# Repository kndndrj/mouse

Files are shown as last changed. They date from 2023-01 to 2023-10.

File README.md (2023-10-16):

# Mouse

Computer mouse from scratch.

This repository serves as an appendix to my master thesis.

New features and bugfixes won't be added to this repository.
I plan on separating different parts of the repository into
a bigger project sometime in the future. If you come across
this repository before I do that, feel free to open an issue here.

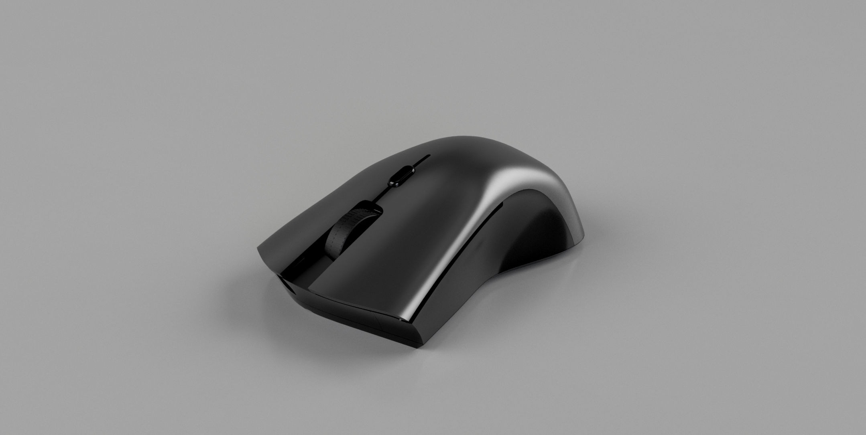
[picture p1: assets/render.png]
render


## Overview

This repository contains blueprints for building a computer mouse.

### PCB

The pcb is made using Kicad with components from LCSC, to support assembly service from JLCPCB.

[more](pcb/)

### Housing

Housing (or case) is designed in Fusion360 and is meant to be 3D printed using SLS (also available on JLCPCB).

[more](housing/)

### Firmware

First iteration of the firmware was written in C using libopencm3 library.
Due to a lack of higher level ergonomics and support for board specific abstractions,
it was later re-written in Rust.

The new version of firmware is split into 2 parts:

- **Drivers for various components** (e.g. sensor, encoder...) are exposed as a library using embedded-hal
  traits as abstraction. It is intended to be portable across different hardware and possibly used in
  other mouse-related projects.
- **Board specific implementation** is essentially just glue-code between hardware specifics and modules
  from the forementioned library.

[more - C](firmware-c/)

[more - Rust](firmware-rust/)

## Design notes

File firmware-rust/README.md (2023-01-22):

# Mouse Firmware in Rust

Rust firmware for computer mice.

This repo is split into two parts:

- `mouse-libs`

  Drivers for mouse components using embedded-hal interfaces.

  [more](mouse-libs/README.md).

- `mouse-fw`

  Specific firmware implementation using the forementioned libraries.

  [more](mouse-fw/README.md).

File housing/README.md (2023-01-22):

# Mouse Housing

Housing for the PCB, designed in Fusion360

[`assembly.f3z`](assembly.f3z) is used for development, then it's exported to `.step`
and `.stl` for previewing and manufacturing.

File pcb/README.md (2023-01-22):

# Mouse PCB
Repository for the mouse circuit board schematics.

Some of the features are:
- PMW3360DM sensor
- STM32F042K6T6 MCU
- Hardware debouncing
- Expansion pins for future upgrades
- USB-C

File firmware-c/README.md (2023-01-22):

# Mouse Firmware in C

Note: Abandoned due to re-implementation in Rust. You might still find something useful when tinkering around here.

Set up the build environment with (order of crossfile flags is important):

```sh
meson setup --cross-file=crossfiles/main.ini --cross-file=crossfiles/stm32/f0.ini build
```

And then compile the code:

```sh
meson compile -C build
```

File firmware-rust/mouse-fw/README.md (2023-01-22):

# Mouse Firmware in Rust - Implementation

Firmware implementation for mouse-pcb.

## Flashing

1. Build

   ```sh
   cargo build --release # for production release
   # or
   cargo build --features="disable_usb" # for dev build without usb support - for debugging
   ```

2. "Extract" the binary

   ```sh
      arm-none-eabi-objcopy -O binary target/thumbv6m-none-eabi/release/mouse-fw-rust out.bin
   ```

3. Flash using your debug probe

   ```sh
   # example using st-link
   st-flash write out.bin 0x08000000
   ```

4. Debug (for development)
   
   Use openocd/st-util/... to set up the gdb server and connect to it using arm-none-eabi-gdb

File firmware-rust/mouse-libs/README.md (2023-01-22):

# Mouse Firmware in Rust - Library

Building blocks for writing your own firmware. It uses "interfaces"
defined by embedded-hal crate to abstract away the hardware. If you want
to use this in your firmware, simply provide the required parameters
(usually in form of trait implementation) and you are good to go.
example:

```rust
// ...init code

// init the parts that implement required traits
let gpioa = p.GPIOA.split(&mut rcc);
let (
    spi_cs,
    spi_sck,
    spi_miso,
    spi_mosi,
    pmw_reset,
) = cortex_m::interrupt::free(move |cs| {
    (
        // SPI pins
        gpioa.pa4.into_push_pull_output(cs),
        gpioa.pa5.into_alternate_af0(cs),
        gpioa.pa6.into_alternate_af0(cs),
        gpioa.pa7.into_alternate_af0(cs),
        // PMW3360 reset pin
        gpioa.pa10.into_push_pull_output(cs),
    )
});
let spi = Spi::spi1(
    p.SPI1,
    (spi_sck, spi_miso, spi_mosi),
    MODE,
    1.mhz(),
    &mut rcc,
);

// finally use that to create a new instance of the driver
let mut pmw = Pmw3360::new(spi, spi_cs, pmw_reset, delay);
// ...
```

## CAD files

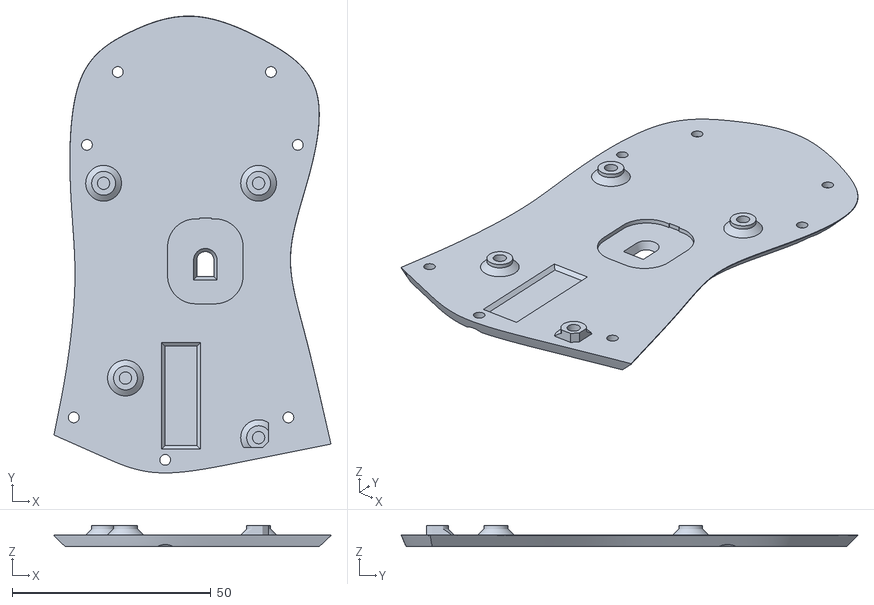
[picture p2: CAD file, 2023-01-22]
housing/stl/bottom.stl
69.7 x 114.9 x 5.40

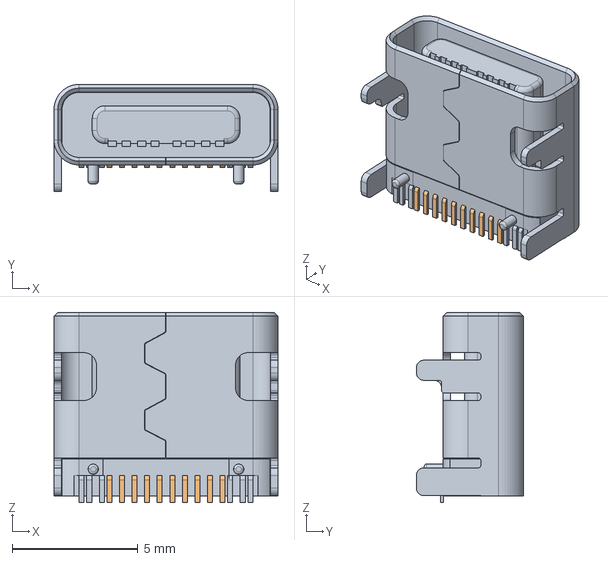
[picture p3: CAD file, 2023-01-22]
pcb/3d/usb_c_u262-16xn-4bvc11.step
8.90 x 4.26 x 7.56 mm

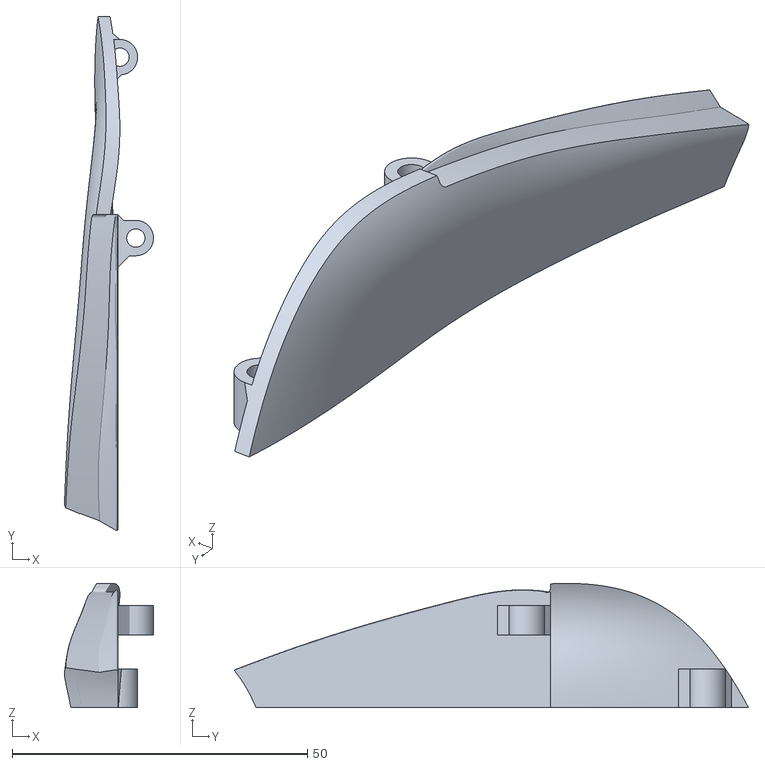
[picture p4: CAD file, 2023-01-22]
housing/stl/right.stl
15.1 x 87.1 x 21.0

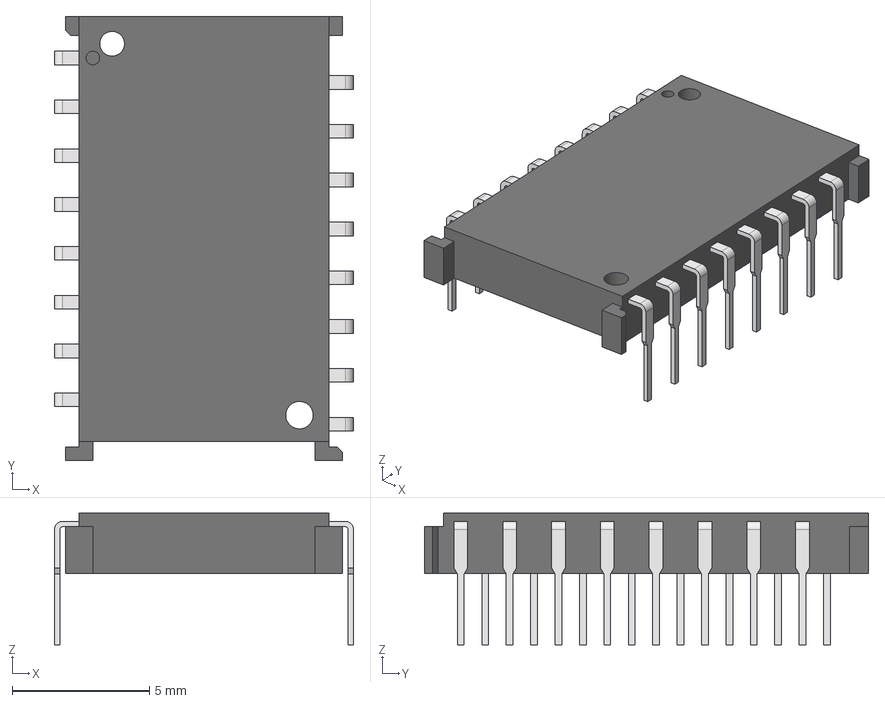
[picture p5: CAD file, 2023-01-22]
pcb/3d/sensor_pmw3360dm.step
10.9 x 16.2 x 4.81 mm
Lead x 8
Lead(Mirror) x 8

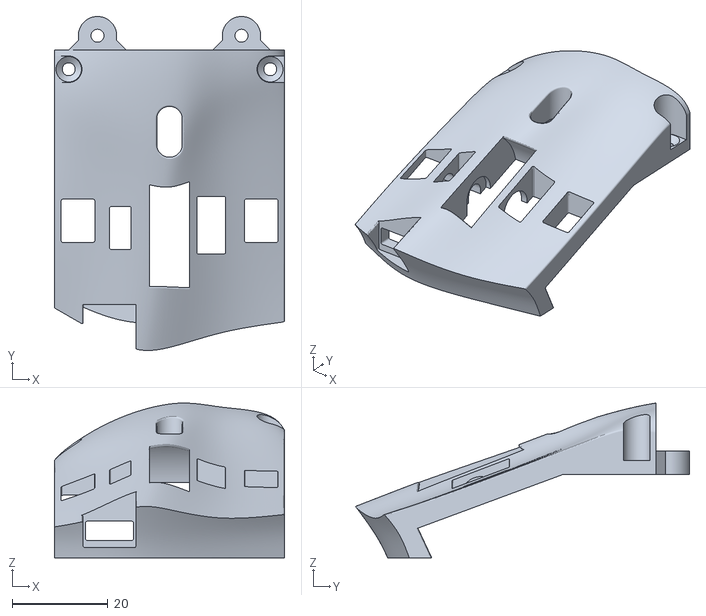
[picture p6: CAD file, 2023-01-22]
housing/stl/middle.stl
48.0 x 69.6 x 32.3

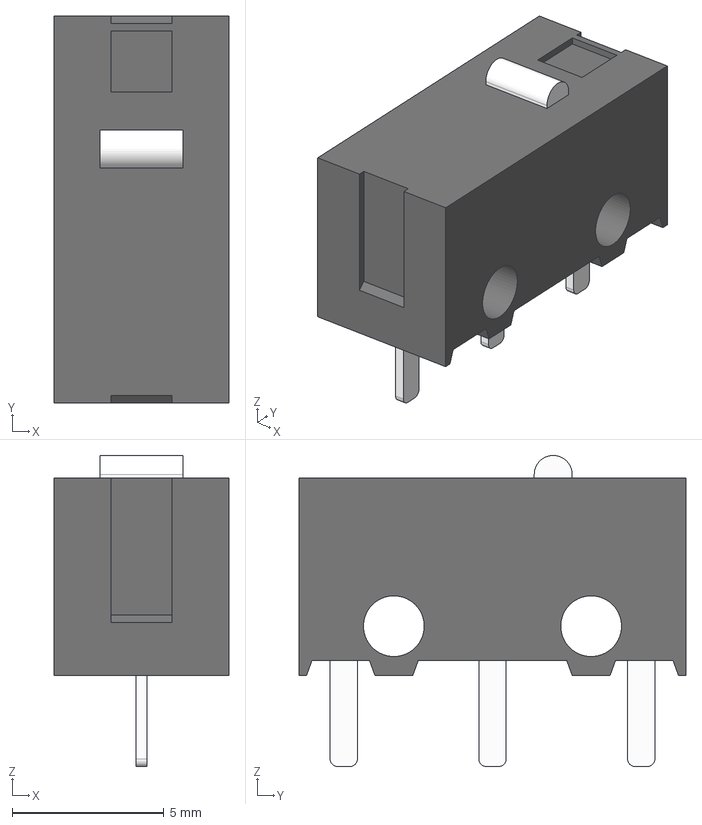
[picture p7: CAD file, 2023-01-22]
pcb/3d/switch_d2fc-f-7n.step
5.75 x 12.8 x 10.2 mm
Switch Body
Pin 2
Button
Pin 3
Pin 1

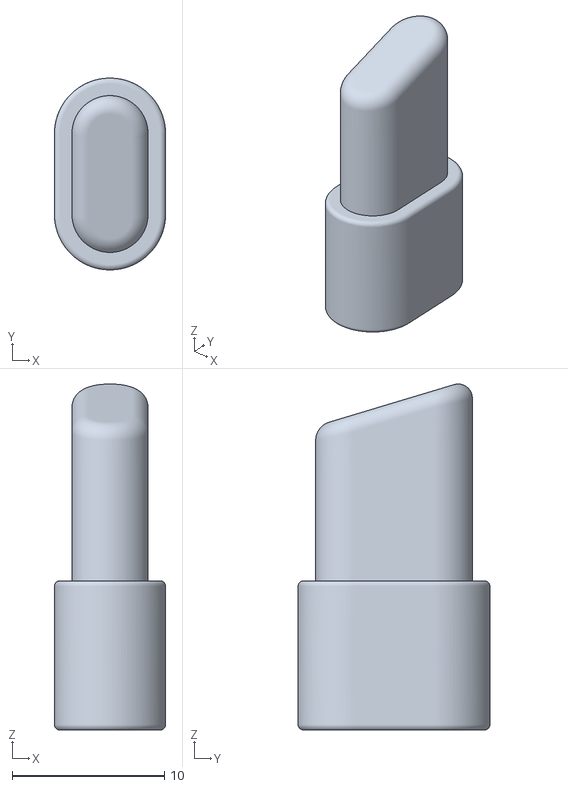
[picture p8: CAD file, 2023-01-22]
housing/stl/button.stl
7.30 x 12.6 x 22.7

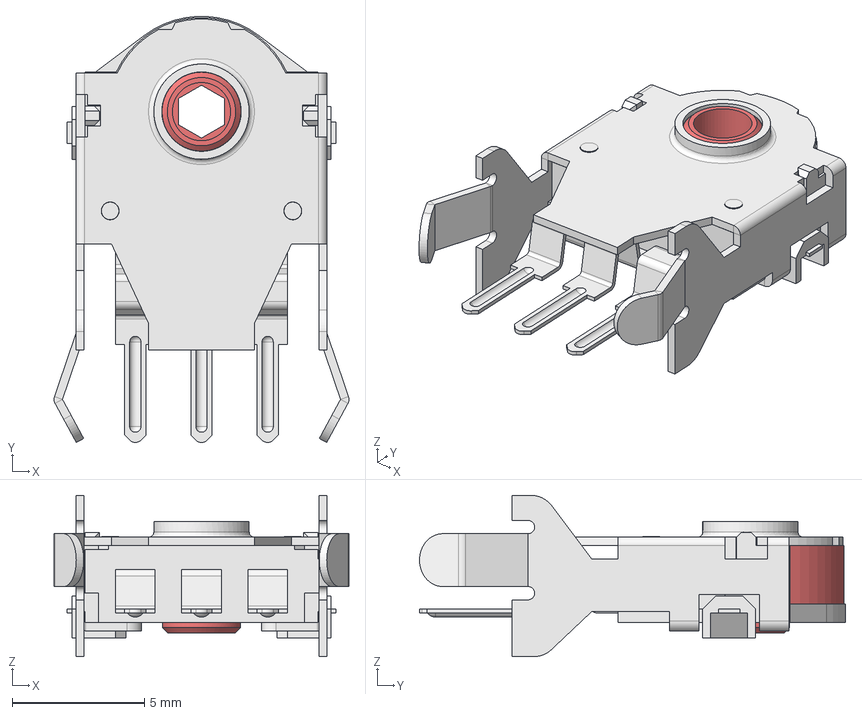
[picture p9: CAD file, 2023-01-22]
pcb/3d/encoder_ec10_9mm.step
11.1 x 16.1 x 6.10 mm

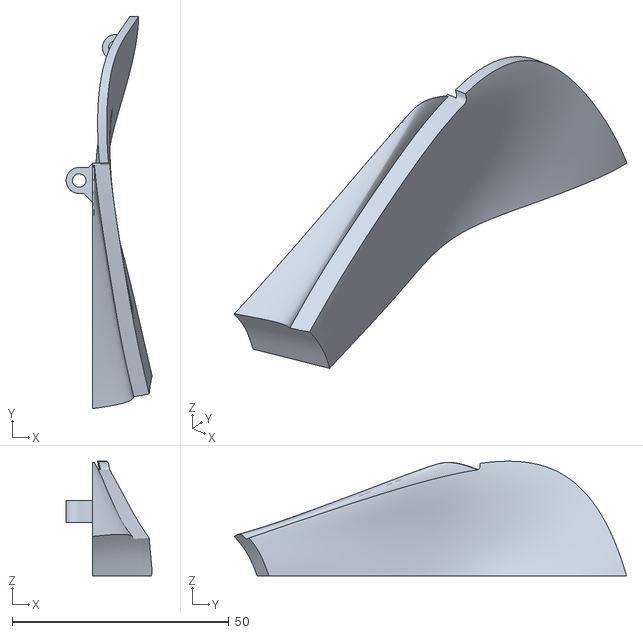
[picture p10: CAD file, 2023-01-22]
housing/stl/left.stl
19.8 x 90.4 x 26.4

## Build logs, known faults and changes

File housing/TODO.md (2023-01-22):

# Mouse Housing TODO

- Add shape joints between parts
- Is there a way of convert to stl using CI

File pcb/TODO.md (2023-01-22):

# Mouse PCB TODO

- Flip sensor 180 degrees (keep lens holes on exactly the same position!!!)
- Adjust encoder clearance (lower right corner touches a cap)
- Left and right expansion pins should have the same arrangement
- Do something with Boot0 pin (must be connected to GND - maybe through a button or a switch?)
- Connect encoder to timer input pins

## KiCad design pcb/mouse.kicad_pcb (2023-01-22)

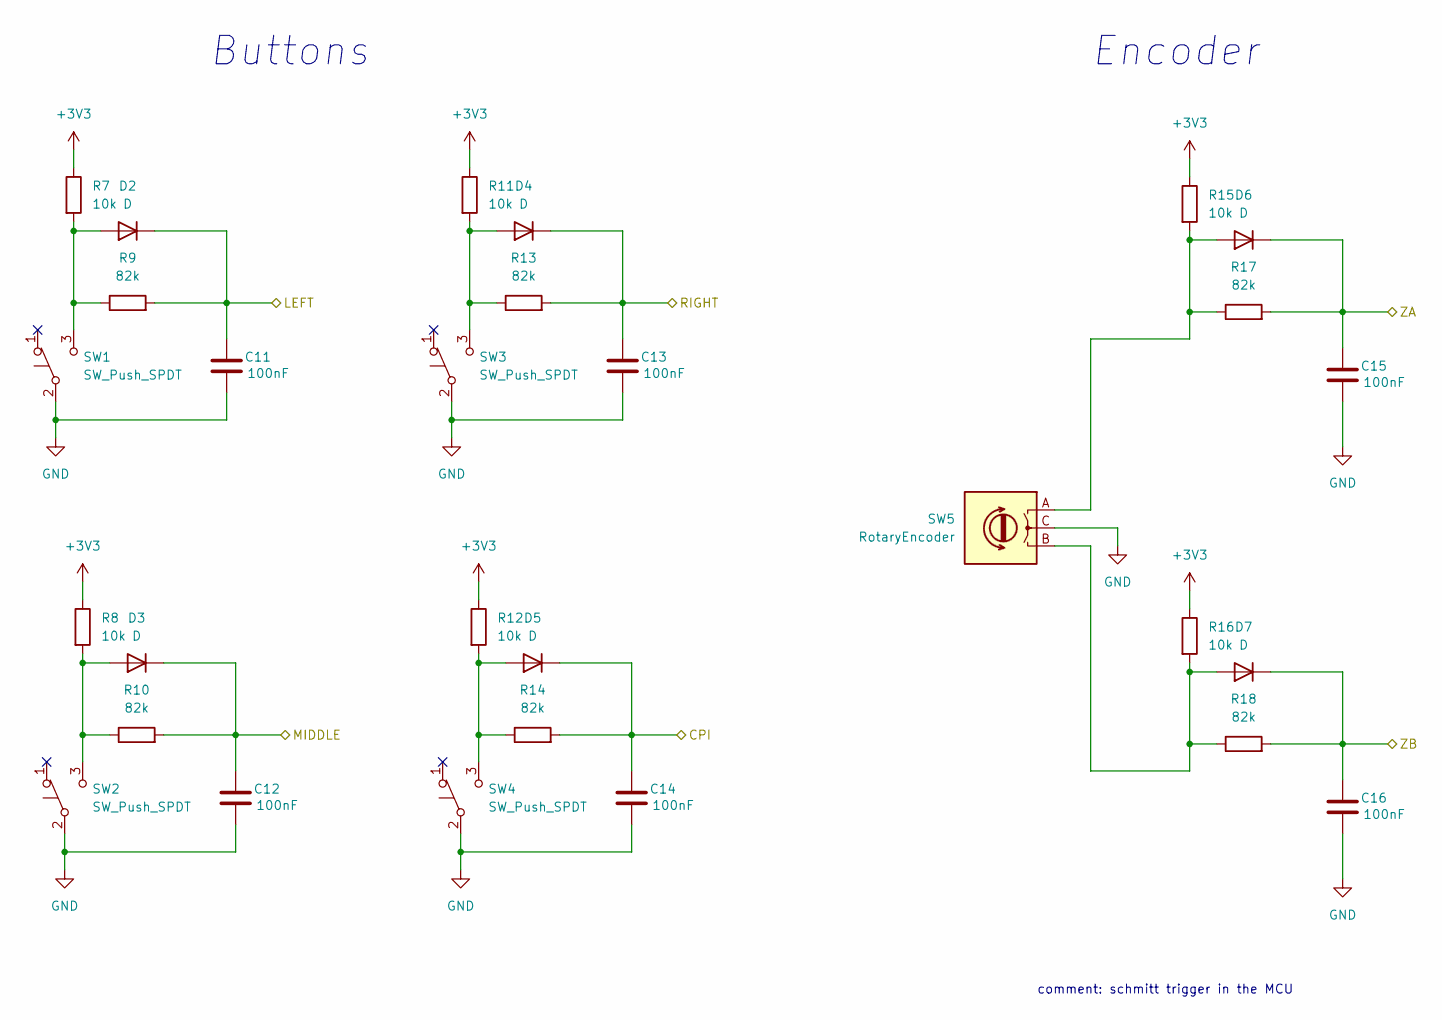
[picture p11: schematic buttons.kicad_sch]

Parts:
C11, C12, C13, C14, C15, C16: 100nF; C_0603_1608Metric; LCSC C14663
D2, D3, D4, D5, D6, D7: D; D_SOD-123F; LCSC C64898
R7, R8, R11, R12, R15, R16: 10k; R_0603_1608Metric; LCSC C25804
R9, R10, R13, R14, R17, R18: 82k; R_0603_1608Metric; LCSC C23254
SW1, SW2, SW3, SW4: SW_Push_SPDT; mouse_switch
SW5: RotaryEncoder; mouse_encoder

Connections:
+3V3: R7.1, R8.1, R11.1, R12.1, R15.1, R16.1; also elsewhere on the board
/buttons/CPI: C14.1, D5.1 (K), R14.2; also elsewhere on the board
/buttons/LEFT: C11.1, D2.1 (K), R9.2; also elsewhere on the board
/buttons/MIDDLE: C12.1, D3.1 (K), R10.2; also elsewhere on the board
/buttons/RIGHT: C13.1, D4.1 (K), R13.2; also elsewhere on the board
/buttons/ZA: C15.1, D6.1 (K), R17.2; also elsewhere on the board
/buttons/ZB: C16.1, D7.1 (K), R18.2; also elsewhere on the board
GND: C11.2, C12.2, C13.2, C14.2, C15.2, C16.2, SW1.2 (B), SW2.2 (B), SW3.2 (B), SW4.2 (B), SW5.C; also elsewhere on the board
unnamed: D2.2 (A), R7.2, R9.1, SW1.3 (C)
unnamed: D3.2 (A), R8.2, R10.1, SW2.3 (C)
unnamed: D4.2 (A), R11.2, R13.1, SW3.3 (C)
unnamed: D5.2 (A), R12.2, R14.1, SW4.3 (C)
unnamed: D6.2 (A), R15.2, R17.1, SW5.A
unnamed: D7.2 (A), R16.2, R18.1, SW5.B

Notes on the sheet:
Encoder
Buttons
comment: schmitt trigger in the MCU

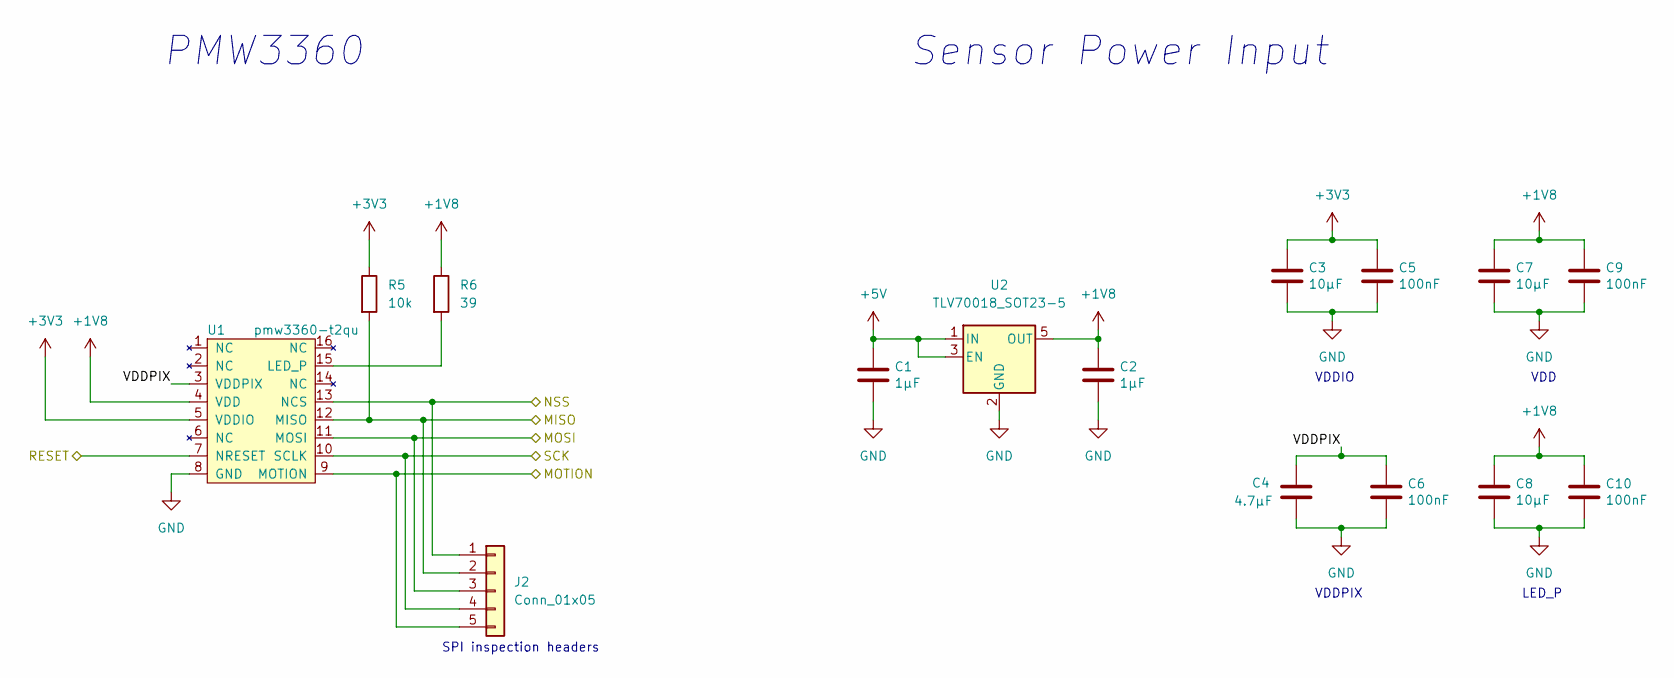
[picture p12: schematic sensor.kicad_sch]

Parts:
C1, C2: 1μF; C_0603_1608Metric; LCSC C15849
C3, C7, C8: 10μF; C_0603_1608Metric; LCSC C19702
C4: 4.7μF; C_0603_1608Metric; LCSC C19666
C5, C6, C9, C10: 100nF; C_0603_1608Metric; LCSC C14663
J2: Conn_01x05; PinHeader_1x05_P2.54mm_Vertical
R5: 10k; R_0603_1608Metric; LCSC C25804
R6: 39; R_0603_1608Metric; LCSC C227890
U1: pmw3360-t2qu
U2: TLV70018_SOT23-5; SOT-23-5; LCSC C79924

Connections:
+1V8: C2.1, C7.1, C8.1, C9.1, C10.1, R6.1, U1.4 (VDD), U2.5 (OUT)
+3V3: C3.1, C5.1, R5.1, U1.5 (VDDIO); also elsewhere on the board
+5V: C1.1, U2.1 (IN), U2.3 (EN); also elsewhere on the board
/mcu/SENSOR_MISO: J2.2, R5.2, U1.12 (MISO); also elsewhere on the board
/mcu/SENSOR_MOSI: J2.3, U1.11 (MOSI); also elsewhere on the board
/mcu/SENSOR_MOTION: J2.5, U1.9 (MOTION); also elsewhere on the board
/mcu/SENSOR_NSS: J2.1, U1.13 (NCS); also elsewhere on the board
/mcu/SENSOR_RESET: U1.7 (NRESET); also elsewhere on the board
/mcu/SENSOR_SCK: J2.4, U1.10 (SCLK); also elsewhere on the board
/sensor/VDDPIX: C4.1, C6.1, U1.3 (VDDPIX)
GND: C1.2, C2.2, C3.2, C4.2, C5.2, C6.2, C7.2, C8.2, C9.2, C10.2, U1.8 (GND), U2.2 (GND); also elsewhere on the board
unnamed: R6.2, U1.15 (LED_P)

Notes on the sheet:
VDDIO
VDD
SPI inspection headers
Sensor Power Input
LED_P
VDDPIX
PMW3360

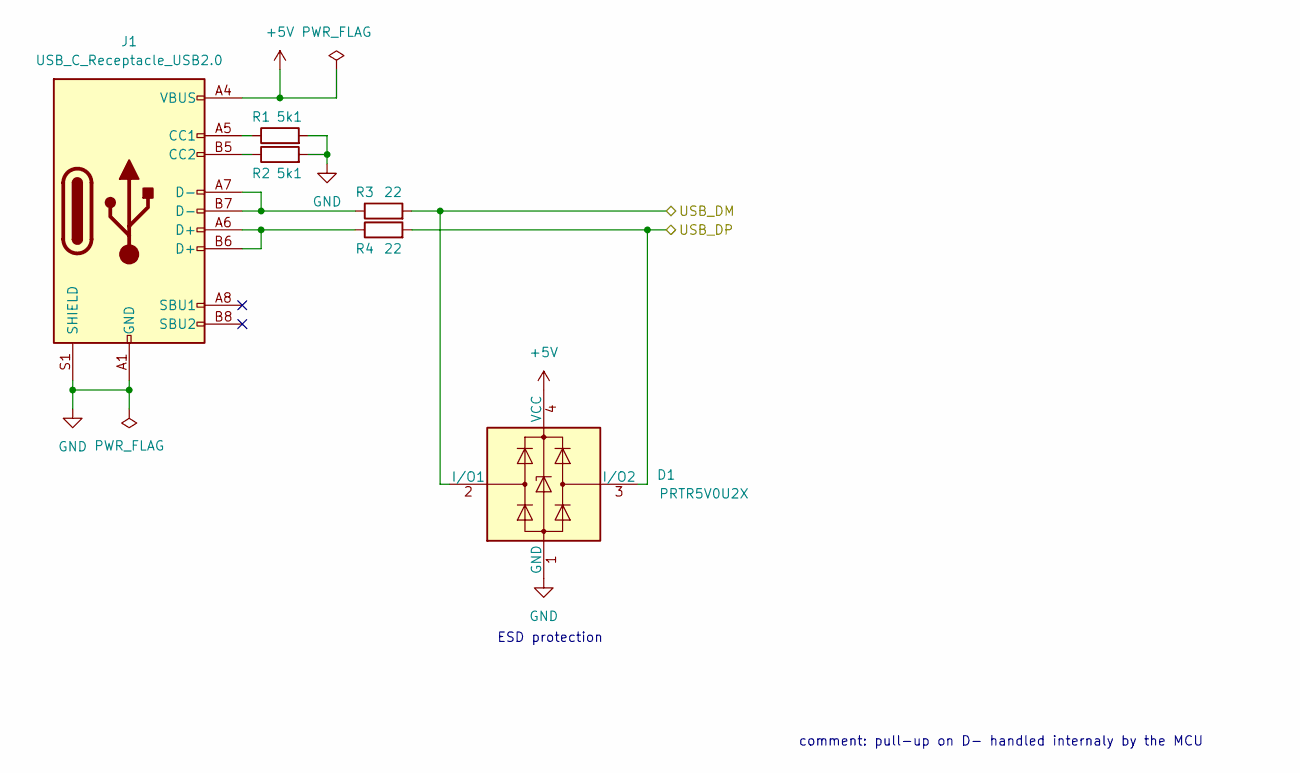
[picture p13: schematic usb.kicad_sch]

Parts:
D1: PRTR5V0U2X; SOT-143; LCSC C2827688
J1: USB_C_Receptacle_USB2.0; USB_C_Receptacle_XKB_U262-16XN-4BVC11; LCSC C319148
R1, R2: 5k1; R_0603_1608Metric; LCSC C23186
R3, R4: 22; R_0603_1608Metric; LCSC C107701

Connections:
+5V: D1.4 (VCC), J1.A4 (VBUS), J1.A9 (VBUS), J1.B4 (VBUS), J1.B9 (VBUS); also elsewhere on the board
/mcu/USB_DM: D1.2 (I/O1), R3.2; also elsewhere on the board
/mcu/USB_DP: D1.3 (I/O2), R4.2; also elsewhere on the board
GND: D1.1 (GND), J1.A1 (GND), J1.A12 (GND), J1.B1 (GND), J1.B12 (GND), J1.S1 (SHIELD), R1.2, R2.2; also elsewhere on the board
unnamed: J1.A5 (CC1), R1.1
unnamed: J1.A6 (D+), J1.B6 (D+), R4.1
unnamed: J1.A7 (D-), J1.B7 (D-), R3.1
unnamed: J1.B5 (CC2), R2.1

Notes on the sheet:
ESD protection
comment: pull-up on D- handled internaly by the MCU

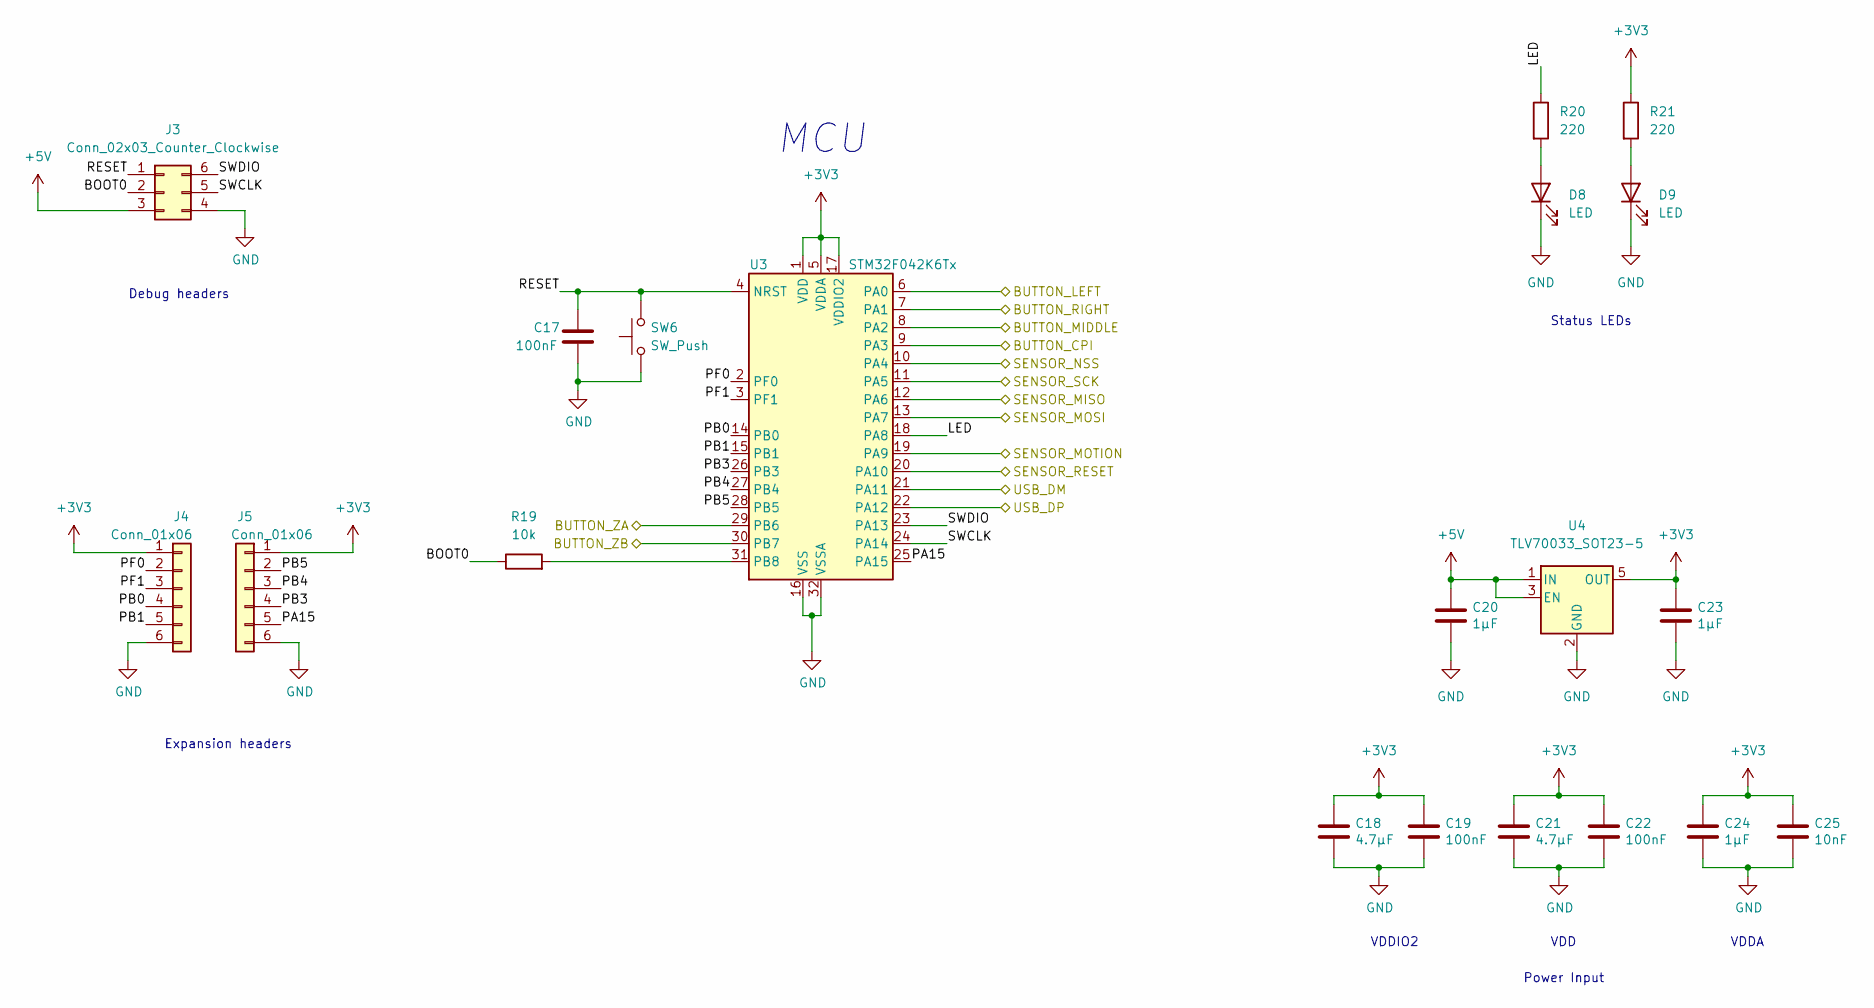
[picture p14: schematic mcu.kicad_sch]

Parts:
C17, C19, C22: 100nF; C_0603_1608Metric; LCSC C14663
C18, C21: 4.7μF; C_0603_1608Metric; LCSC C19666
C20, C23, C24: 1μF; C_0603_1608Metric; LCSC C15849
C25: 10nF; C_0603_1608Metric; LCSC C57112
D8, D9: LED; LED_0603_1608Metric; LCSC C72038
J3: Conn_02x03_Counter_Clockwise; PinHeader_2x03_P2.54mm_Vertical
J4, J5: Conn_01x06; PinSocket_1x06_P2.54mm_Vertical
R19: 10k; R_0603_1608Metric; LCSC C25804
R20, R21: 220; R_0603_1608Metric; LCSC C22962
SW6: SW_Push; SW_PUSH_6mm
U3: STM32F042K6Tx; LQFP-32_7x7mm_P0.8mm; LCSC C69216
U4: TLV70033_SOT23-5; SOT-23-5; LCSC C11337

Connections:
+3V3: C18.1, C19.1, C21.1, C22.1, C23.1, C24.1, C25.1, J4.1, J5.1, R21.1, U3.1 (VDD), U3.5 (VDDA), U3.17 (VDDIO2), U4.5 (OUT); also elsewhere on the board
+5V: C20.1, J3.3, U4.1 (IN), U4.3 (EN); also elsewhere on the board
/buttons/CPI: U3.9 (PA3); also elsewhere on the board
/buttons/LEFT: U3.6 (PA0); also elsewhere on the board
/buttons/MIDDLE: U3.8 (PA2); also elsewhere on the board
/buttons/RIGHT: U3.7 (PA1); also elsewhere on the board
/buttons/ZA: U3.29 (PB6); also elsewhere on the board
/buttons/ZB: U3.30 (PB7); also elsewhere on the board
/mcu/BOOT0: J3.2, R19.1
/mcu/LED: R20.1, U3.18 (PA8)
/mcu/PA15: J5.5, U3.25 (PA15)
/mcu/PB0: J4.4, U3.14 (PB0)
/mcu/PB1: J4.5, U3.15 (PB1)
/mcu/PB3: J5.4, U3.26 (PB3)
/mcu/PB4: J5.3, U3.27 (PB4)
/mcu/PB5: J5.2, U3.28 (PB5)
/mcu/PF0: J4.2, U3.2 (PF0)
/mcu/PF1: J4.3, U3.3 (PF1)
/mcu/RESET: C17.1, J3.1, SW6.2, U3.4 (NRST)
/mcu/SENSOR_MISO: U3.12 (PA6); also elsewhere on the board
/mcu/SENSOR_MOSI: U3.13 (PA7); also elsewhere on the board
/mcu/SENSOR_MOTION: U3.19 (PA9); also elsewhere on the board
/mcu/SENSOR_NSS: U3.10 (PA4); also elsewhere on the board
/mcu/SENSOR_RESET: U3.20 (PA10); also elsewhere on the board
/mcu/SENSOR_SCK: U3.11 (PA5); also elsewhere on the board
/mcu/SWCLK: J3.5, U3.24 (PA14)
/mcu/SWDIO: J3.6, U3.23 (PA13)
/mcu/USB_DM: U3.21 (PA11); also elsewhere on the board
/mcu/USB_DP: U3.22 (PA12); also elsewhere on the board
GND: C17.2, C18.2, C19.2, C20.2, C21.2, C22.2, C23.2, C24.2, C25.2, D8.1 (K), D9.1 (K), J3.4, J4.6, J5.6, SW6.1, U3.16 (VSS), U3.32 (VSSA), U4.2 (GND); also elsewhere on the board
unnamed: D8.2 (A), R20.2
unnamed: D9.2 (A), R21.2
unnamed: R19.2, U3.31 (PB8)

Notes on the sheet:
Power Input
VDD
MCU
Debug headers
VDDIO2
Status LEDs
VDDA
Expansion headers

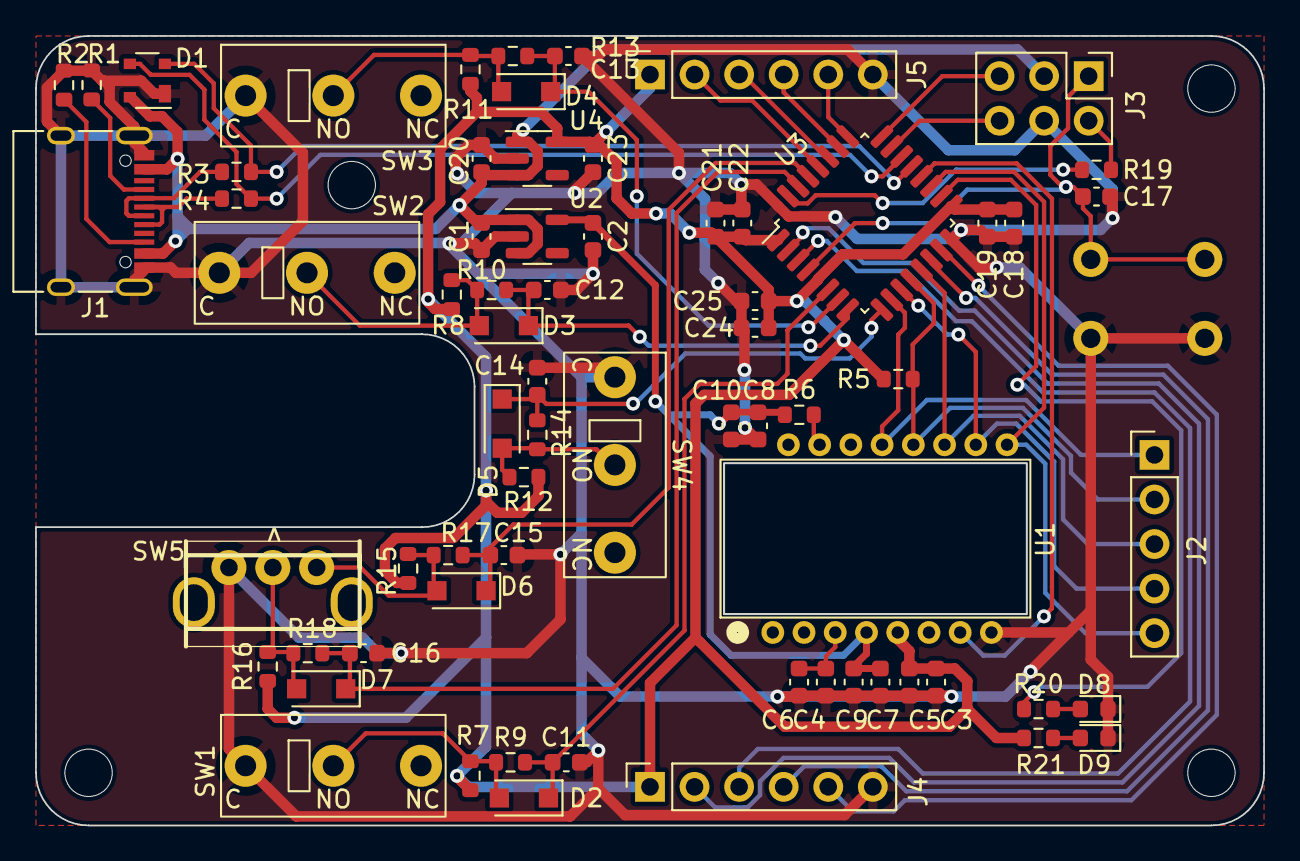
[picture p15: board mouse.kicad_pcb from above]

Board: 2 copper layers, 70.0 x 45.0 mm, 70 parts (1 on the bottom side), 46 nets.

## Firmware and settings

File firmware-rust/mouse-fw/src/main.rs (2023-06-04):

#![no_std]
#![no_main]

use panic_halt as _;

use packed_struct::prelude::*;

use stm32f0xx_hal::spi::{Mode, Phase, Polarity, Spi};
use stm32f0xx_hal::{delay::Delay, pac, prelude::*};

use usbd_human_interface_device::device::mouse::WheelMouseReport;

#[cfg(not(feature = "disable_usb"))]
use {
    fugit::ExtU32,
    stm32f0xx_hal::usb::{Peripheral, UsbBus},
    usb_device::prelude::*,
    usbd_human_interface_device::{
        device::mouse::WHEEL_MOUSE_REPORT_DESCRIPTOR,
        prelude::*,
        {
            hid_class::{prelude::InterfaceProtocol, UsbPacketSize},
            interface::raw::RawInterfaceBuilder,
        },
    },
};

use cortex_m;
use cortex_m_rt::entry;

use mouse_libs::{
    debouncer::{self, Debouncer},
    encoder::Encoder,
    pmw3360::Pmw3360,
};

#[entry]
fn main() -> ! {
    let mut p = pac::Peripherals::take().unwrap();
    let cp = cortex_m::Peripherals::take().unwrap();

    // Clock
    let mut rcc = p
        .RCC
        .configure()
        .hsi48()
        .enable_crs(p.CRS)
        .sysclk(48.mhz())
        .pclk(24.mhz())
        .freeze(&mut p.FLASH);

    // Pin maps
    let gpioa = p.GPIOA.split(&mut rcc);
    let (
        button_left,
        button_right,
        button_middle,
        button_cpi,
        spi_cs,
        spi_sck,
        spi_miso,
        spi_mosi,
        pmw_reset,
        usb_dm,
        usb_dp,
    ) = cortex_m::interrupt::free(move |cs| {
        (
            // Button pins
            gpioa.pa0,
            gpioa.pa1,
            gpioa.pa2,
            gpioa.pa3,
            // SPI pins
            gpioa.pa4.into_push_pull_output(cs),
            gpioa.pa5.into_alternate_af0(cs),
            gpioa.pa6.into_alternate_af0(cs),
            gpioa.pa7.into_alternate_af0(cs),
            // PMW3360 reset pin
            gpioa.pa10.into_push_pull_output(cs),
            // USB pins
            gpioa.pa11,
            gpioa.pa12,
        )
    });

    let gpiob = p.GPIOB.split(&mut rcc);
    let (enc_a, enc_b) = cortex_m::interrupt::free(move |_| {
        (
            // Encoder pins
            gpiob.pb6, gpiob.pb7,
        )
    });

    // SPI
    const MODE: Mode = Mode {
        polarity: Polarity::IdleHigh,
        phase: Phase::CaptureOnSecondTransition,
    };
    let spi = Spi::spi1(
        p.SPI1,
        (spi_sck, spi_miso, spi_mosi),
        MODE,
        1.mhz(),
        &mut rcc,
    );

    // Delay
    let delay = Delay::new(cp.SYST, &rcc);

    // Sensor
    let mut pmw = Pmw3360::new(spi, spi_cs, pmw_reset, delay);
    pmw.set_cpi(1200).unwrap_or_default();

    // Encoder
    let mut enc = Encoder::new(enc_a, enc_b);

    // Debouncer for cpi pin
    let mut debouncer_cpi = Debouncer::new(8);

    // USB
    // NOTE: keep usb last before loop -> might not enumerate fast enough
    #[cfg(not(feature = "disable_usb"))]
    let usb_bus = UsbBus::new(Peripheral {
        usb: p.USB,
        pin_dm: usb_dm,
        pin_dp: usb_dp,
    });
    #[cfg(not(feature = "disable_usb"))]
    let mut mouse = UsbHidClassBuilder::new()
        .add_interface(
            RawInterfaceBuilder::new(WHEEL_MOUSE_REPORT_DESCRIPTOR)
                .boot_device(InterfaceProtocol::Mouse)
                .description("Wheel Mouse")
                .in_endpoint(UsbPacketSize::Bytes8, 1.millis())
                .unwrap()
                .without_out_endpoint()
                .build(),
        )
        .build(&usb_bus);
    // USB_SERIAL_NUMBER defined in build.rs at compile time
    #[cfg(not(feature = "disable_usb"))]
    let mut usb_dev = UsbDeviceBuilder::new(&usb_bus, UsbVidPid(0xc410, 0x0000))
        .manufacturer("kndndrj")
        .product("mouse")
        .serial_number(env!("USB_SERIAL_NUMBER"))
        .build();

    let mut report = WheelMouseReport::default();

    loop {
        #[cfg(not(feature = "disable_usb"))]
        {

            if !usb_dev.poll(&mut [&mut mouse]) {
                continue;
            }

            mouse.interface().write_report(&report.pack().unwrap()).ok();
        }

        report = WheelMouseReport::default();

        let motion_data = pmw.burst_read().unwrap_or_default();

        if motion_data.motion && motion_data.on_surface {
            if motion_data.dx > 127 {
                report.x = -127;
            } else if motion_data.dx < -127 {
                report.x = 127;
            } else {
                report.x = -motion_data.dx as i8;
            }

            if motion_data.dy > 127 {
                report.y = -127;
            } else if motion_data.dy < -127 {
                report.y = 127;
            } else {
                report.y = -motion_data.dy as i8;
            }
        }

        enc.update().ok();

        if report.vertical_wheel == 0 {
            report.vertical_wheel = enc.read().unwrap_or_default().count();
        }

        if button_left.is_low().unwrap_or_default() {
            report.buttons = report.buttons | (1 << 0);
        }
        if button_right.is_low().unwrap_or_default() {
            report.buttons = report.buttons | (1 << 1);
        }
        if button_middle.is_low().unwrap_or_default() {
            report.buttons = report.buttons | (1 << 2);
        }
        // Debouncer is meant to be used with a scheduler, but the buttons on our pcb are very well
        // hw debounced, so we use it to detect the edge
        let cpi_button_state = debouncer_cpi
            .update(button_cpi.is_high().unwrap_or_default())
            .unwrap_or_default();
        if cpi_button_state == debouncer::State::Low {
            let mut cpi = pmw.get_cpi().unwrap_or_default() + 2000;
            if cpi > 12000 {
                cpi = 0;
            }
            pmw.set_cpi(cpi).unwrap_or_default();
        }
    }
}

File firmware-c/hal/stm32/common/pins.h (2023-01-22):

#ifndef HAL_PINS_H
#define HAL_PINS_H

#include <libopencm3/stm32/gpio.h>
#include <libopencm3/stm32/rcc.h>
#include <stdint.h>

typedef struct port_pin {
  uint32_t port;
  uint32_t pin;
  uint32_t rcc;
} io_t;

#define PORT_PIN(port, pin, rcc) \
  (io_t) { port, pin, rcc }
#define PORT(port_pin) port_pin.port
#define PIN(port_pin) port_pin.pin
#define RCC_PORT(port_pin) port_pin.rcc

#define IO_A0 PORT_PIN(GPIOA, GPIO0, RCC_GPIOA)
#define IO_A1 PORT_PIN(GPIOA, GPIO1, RCC_GPIOA)
#define IO_A2 PORT_PIN(GPIOA, GPIO2, RCC_GPIOA)
#define IO_A3 PORT_PIN(GPIOA, GPIO3, RCC_GPIOA)
#define IO_A4 PORT_PIN(GPIOA, GPIO4, RCC_GPIOA)
#define IO_A5 PORT_PIN(GPIOA, GPIO5, RCC_GPIOA)
#define IO_A6 PORT_PIN(GPIOA, GPIO6, RCC_GPIOA)
#define IO_A7 PORT_PIN(GPIOA, GPIO7, RCC_GPIOA)
#define IO_A8 PORT_PIN(GPIOA, GPIO8, RCC_GPIOA)
#define IO_A9 PORT_PIN(GPIOA, GPIO9, RCC_GPIOA)
#define IO_A10 PORT_PIN(GPIOA, GPIO10, RCC_GPIOA)
#define IO_A11 PORT_PIN(GPIOA, GPIO11, RCC_GPIOA)
#define IO_A12 PORT_PIN(GPIOA, GPIO12, RCC_GPIOA)
#define IO_A13 PORT_PIN(GPIOA, GPIO13, RCC_GPIOA)
#define IO_A14 PORT_PIN(GPIOA, GPIO14, RCC_GPIOA)
#define IO_A15 PORT_PIN(GPIOA, GPIO15, RCC_GPIOA)

#define IO_B0 PORT_PIN(GPIOB, GPIO0, RCC_GPIOB)
#define IO_B1 PORT_PIN(GPIOB, GPIO1, RCC_GPIOB)
#define IO_B2 PORT_PIN(GPIOB, GPIO2, RCC_GPIOB)
#define IO_B3 PORT_PIN(GPIOB, GPIO3, RCC_GPIOB)
#define IO_B4 PORT_PIN(GPIOB, GPIO4, RCC_GPIOB)
#define IO_B5 PORT_PIN(GPIOB, GPIO5, RCC_GPIOB)
#define IO_B6 PORT_PIN(GPIOB, GPIO6, RCC_GPIOB)
#define IO_B7 PORT_PIN(GPIOB, GPIO7, RCC_GPIOB)
#define IO_B8 PORT_PIN(GPIOB, GPIO8, RCC_GPIOB)
#define IO_B9 PORT_PIN(GPIOB, GPIO9, RCC_GPIOB)
#define IO_B10 PORT_PIN(GPIOB, GPIO10, RCC_GPIOB)
#define IO_B11 PORT_PIN(GPIOB, GPIO11, RCC_GPIOB)
#define IO_B12 PORT_PIN(GPIOB, GPIO12, RCC_GPIOB)
#define IO_B13 PORT_PIN(GPIOB, GPIO13, RCC_GPIOB)
#define IO_B14 PORT_PIN(GPIOB, GPIO14, RCC_GPIOB)
#define IO_B15 PORT_PIN(GPIOB, GPIO15, RCC_GPIOB)

#define IO_C0 PORT_PIN(GPIOC, GPIO0, RCC_GPIOC)
#define IO_C1 PORT_PIN(GPIOC, GPIO1, RCC_GPIOC)
#define IO_C2 PORT_PIN(GPIOC, GPIO2, RCC_GPIOC)
#define IO_C3 PORT_PIN(GPIOC, GPIO3, RCC_GPIOC)
#define IO_C4 PORT_PIN(GPIOC, GPIO4, RCC_GPIOC)
#define IO_C5 PORT_PIN(GPIOC, GPIO5, RCC_GPIOC)
#define IO_C6 PORT_PIN(GPIOC, GPIO6, RCC_GPIOC)
#define IO_C7 PORT_PIN(GPIOC, GPIO7, RCC_GPIOC)
#define IO_C8 PORT_PIN(GPIOC, GPIO8, RCC_GPIOC)
#define IO_C9 PORT_PIN(GPIOC, GPIO9, RCC_GPIOC)
#define IO_C10 PORT_PIN(GPIOC, GPIO10, RCC_GPIOC)
#define IO_C11 PORT_PIN(GPIOC, GPIO11, RCC_GPIOC)
#define IO_C12 PORT_PIN(GPIOC, GPIO12, RCC_GPIOC)
#define IO_C13 PORT_PIN(GPIOC, GPIO13, RCC_GPIOC)
#define IO_C14 PORT_PIN(GPIOC, GPIO14, RCC_GPIOC)
#define IO_C15 PORT_PIN(GPIOC, GPIO15, RCC_GPIOC)

#define IO_D0 PORT_PIN(GPIOD, GPIO0, RCC_GPIOD)
#define IO_D1 PORT_PIN(GPIOD, GPIO1, RCC_GPIOD)
#define IO_D2 PORT_PIN(GPIOD, GPIO2, RCC_GPIOD)
#define IO_D3 PORT_PIN(GPIOD, GPIO3, RCC_GPIOD)
#define IO_D4 PORT_PIN(GPIOD, GPIO4, RCC_GPIOD)
#define IO_D5 PORT_PIN(GPIOD, GPIO5, RCC_GPIOD)
#define IO_D6 PORT_PIN(GPIOD, GPIO6, RCC_GPIOD)
#define IO_D7 PORT_PIN(GPIOD, GPIO7, RCC_GPIOD)
#define IO_D8 PORT_PIN(GPIOD, GPIO8, RCC_GPIOD)
#define IO_D9 PORT_PIN(GPIOD, GPIO9, RCC_GPIOD)
#define IO_D10 PORT_PIN(GPIOD, GPIO10, RCC_GPIOD)
#define IO_D11 PORT_PIN(GPIOD, GPIO11, RCC_GPIOD)
#define IO_D12 PORT_PIN(GPIOD, GPIO12, RCC_GPIOD)
#define IO_D13 PORT_PIN(GPIOD, GPIO13, RCC_GPIOD)
#define IO_D14 PORT_PIN(GPIOD, GPIO14, RCC_GPIOD)
#define IO_D15 PORT_PIN(GPIOD, GPIO15, RCC_GPIOD)

#define IO_E0 PORT_PIN(GPIOE, GPIO0, RCC_GPIOE)
#define IO_E1 PORT_PIN(GPIOE, GPIO1, RCC_GPIOE)
#define IO_E2 PORT_PIN(GPIOE, GPIO2, RCC_GPIOE)
#define IO_E3 PORT_PIN(GPIOE, GPIO3, RCC_GPIOE)
#define IO_E4 PORT_PIN(GPIOE, GPIO4, RCC_GPIOE)
#define IO_E5 PORT_PIN(GPIOE, GPIO5, RCC_GPIOE)
#define IO_E6 PORT_PIN(GPIOE, GPIO6, RCC_GPIOE)
#define IO_E7 PORT_PIN(GPIOE, GPIO7, RCC_GPIOE)
#define IO_E8 PORT_PIN(GPIOE, GPIO8, RCC_GPIOE)
#define IO_E9 PORT_PIN(GPIOE, GPIO9, RCC_GPIOE)
#define IO_E10 PORT_PIN(GPIOE, GPIO10, RCC_GPIOE)
#define IO_E11 PORT_PIN(GPIOE, GPIO11, RCC_GPIOE)
#define IO_E12 PORT_PIN(GPIOE, GPIO12, RCC_GPIOE)
#define IO_E13 PORT_PIN(GPIOE, GPIO13, RCC_GPIOE)
#define IO_E14 PORT_PIN(GPIOE, GPIO14, RCC_GPIOE)
#define IO_E15 PORT_PIN(GPIOE, GPIO15, RCC_GPIOE)
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

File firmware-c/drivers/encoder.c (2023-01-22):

#include "encoder.h"

#include "hal/delay.h"
#include "hal/gpio.h"

void ENCODER_init(io_t channel_a, io_t channel_b) {
  // TODO: also allow internal pullup and pulldown
  GPIO_init(channel_a, GPIO_MODE_INPUT_NONE);
  GPIO_init(channel_b, GPIO_MODE_INPUT_NONE);
}

encoder_state_t ENCODER_read(io_t channel_a, io_t channel_b) {
  static int8_t prev = 0x00;

  // read current state
  uint8_t current = 0x00;
  // 0b00000011
  //         ^^
  //         ||
  //   cur_a/ \cur_b

  if (GPIO_status(channel_a)) {
    current |= 1 << 1;
  }
  if (GPIO_status(channel_b)) {
    current |= 1 << 0;
  }

  if (prev == current) {
    return ENCODER_NONE;
  }

  uint8_t state = (prev << 2) | current;
  // determine direction based on state
  // We only care about leading edges -> cw: a, c   ccw: d, b
  // prev_a\ /prev_b
  //       ||
  //       vv
  // 0b00001111
  //         ^^
  //         ||
  //   cur_a/ \cur_b
  //            _____       _____       _____
  //           |     |     |     |     |     |
  // ch A  ____|     |_____|     |_____|     |____
  //
  //           :  :  :  :  :  :  :  :  :  :  :  :
  //      __       _____       _____       _____
  //        |     |     |     |     |     |     |
  // ch B   |_____|     |_____|     |_____|     |__
  //
  //           :  :  :  :  :  :  :  :  :  :  :  :
  // event     a  b  c  d  a  b  c  d  a  b  c  d

  // Debounce delay 1ms
  DELAY_us(1000);

  prev = current;

  switch (state) {
    // cw
    case 0b0010: // a
    case 0b1101: // c
      return ENCODER_CLOCKWISE;
    // ccw
    case 0b0001: // d
    case 0b1110: // b
      return ENCODER_COUNTER_CLOCKWISE;
  }

  return ENCODER_NONE;
}

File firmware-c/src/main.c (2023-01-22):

#include <libopencm3/stm32/rcc.h>

#include "drivers/button.h"
#include "drivers/encoder.h"
#include "drivers/sensors/pmw3360.h"
#include "hal/delay.h"
#include "hal/gpio.h"
#include "hal/spi.h"
#include "hal/usb.h"
#include "pins.h"

int main(void) {
  // clock setup
  rcc_clock_setup_in_hsi_out_48mhz();

  DELAY_init();

  usb_driver_t usb_driver = USB_init();

  ENCODER_init(IO_B6, IO_B7);

  // status LED
  GPIO_init(IO_A8, GPIO_MODE_OUTPUT_PUSHPULL);
  GPIO_clear(IO_A8);

  BUTTON_init(IO_A0);
  BUTTON_init(IO_A1);
  BUTTON_init(IO_A2);

  // start at 800 dpi
  bool isvalid = PMW3360_init(0x32);

  while (1) {
    if (!isvalid) {
      GPIO_toggle(IO_A8);
      DELAY_us(60000);
      isvalid = PMW3360_init(0x32);
    }
    USB_poll(usb_driver);

    uint8_t buf[4] = {0, 0, 0, 0};

    // Buttons
    bool button_left = BUTTON_read(IO_A0);
    bool button_right = BUTTON_read(IO_A1);
    bool button_middle = BUTTON_read(IO_A2);

    if (!button_left) {
      buf[0] |= 1 << 0;
    }
    if (!button_right) {
      buf[0] |= 1 << 1;
    }
    if (!button_middle) {
      buf[0] |= 1 << 2;
    }

    // Wheel
    encoder_state_t encoder = ENCODER_read(IO_B6, IO_B7);

    if (encoder == ENCODER_CLOCKWISE) {
      buf[3] = (uint8_t)1;
    } else if (encoder == ENCODER_COUNTER_CLOCKWISE) {
      buf[3] = (uint8_t)-1;
    }

    // Sensor
    pmw3360_burst_data_t motion_data = PMW3360_read_burst();

    if (motion_data.motion && motion_data.on_surface) {
      if (motion_data.dx > 32767) {
        buf[1] = 65535 - motion_data.dx;
      } else {
        buf[1] = -motion_data.dx;
      }
      if (motion_data.dy > 32767) {
        buf[2] = 65535 - motion_data.dy;
      } else {
        buf[2] = -motion_data.dy;
      }
    }

    USB_write_packet(usb_driver, buf);
  }
}

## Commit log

2021-12-07 Initial commit - rough example with sensor and usb
2021-12-12 added gpio setup for buttons and encoder
2021-12-29 - pmw3360 symbol - basic circuit for stm32f042
    [mouse.kicad_pcb, mouse.sch]
2021-12-31 finished rough outline of the pcb, added gitignore
    [mouse.kicad_sch]
2021-12-31 updated to new kicad file extensions
    [mouse.sch]
2022-01-29 - added power input LDOs - broken out schematics to multiple sheets
    [buttons.kicad_sch, mouse.kicad_sch, sensor.kicad_sch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]
2022-01-29 added pmw3360 footprint and linked it to the symbol
2022-02-03 cleaned up symbols in schematics a bit
    [buttons.kicad_sch, mouse.kicad_sch, sensor.kicad_sch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]
2022-03-06 - split schematic to lists - changed global ports to local - assigned footprints to majority of schematic parts
    [buttons.kicad_sch, mcu.kicad_sch, mouse.kicad_sch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]
2022-05-29 - added debouncing to buttons - assigned some footprints - added expansion and inspection pin headers
    [buttons.kicad_sch, mcu.kicad_sch, mouse.kicad_sch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]
2022-05-29 - added rotary encoder debouncing - added mouse switch and encoder footprints - changed some symbols - assigned footprints
    [buttons.kicad_sch, mcu.kicad_sch, mouse.kicad_sch]
2022-06-12 added LCSC part numbers and assigned footprints
    [buttons.kicad_sch, mcu.kicad_sch, mouse.kicad_sch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]
2022-06-12 - added status leds - changed some lcsc components
    [mcu.kicad_sch, mouse.kicad_sch, sensor.kicad_sch]
2022-06-12 - cleaned up schematics - roughly arranged components on pcb - added pcb outline
    [buttons.kicad_sch, mcu.kicad_sch, mouse.kicad_pcb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]
2022-06-19 - added boot select resistor - regenerated netlist - adjusted pcb component placement
    [buttons.kicad_sch, mcu.kicad_sch, mouse.kicad_pcb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]
2022-06-19 connected all pcb elements with tracks
    [mcu.kicad_sch, mouse.kicad_pcb]
2022-06-19 added pcb mounting holes
    [mouse.kicad_pcb]
2022-06-19 fixed pcb according to DRC check
    [mouse.kicad_pcb]
2022-06-19 added rounded corners to pcb
    [mouse.kicad_pcb]
2022-06-24 manually connected GND on pcb
    [mcu.kicad_sch, mouse.kicad_pcb, mouse.kicad_sch]
2022-06-24 connected long loose ends of pcb traces, repoured copper pours
    [mouse.kicad_pcb]
2022-06-26 updated encoder position and widened wheel gap
    [mouse.kicad_pcb]
2022-06-26 adjusted encoder position
    [mouse.kicad_pcb]
2022-06-26 added usb and sensor 3d models
    [mouse.kicad_pcb, sensor_pmw3360dm.step, usb_c_u262-16xn-4bvc11.step]
2022-06-26 changed 3d models to wrl
    [mouse.kicad_pcb]
2022-06-30 Updated usb connector placement on pcb
    [mouse.kicad_pcb]
2022-07-03 added fabrication files
    [bom.csv, mouse.kicad_pcb, pp.csv]
2022-08-24 - added README.md - renamed include to inc - code cleanup - meson run_command fix
    [main.c, pmw3360.c]
2022-11-20 - adjusted motion burst read for stm32f0 - adjusted poll interval for usb hid endpoint
2022-11-28 - added formatting rules - restructured project: - hal - hw access per architecture - drivers - interaction with chips, buttons etc.
2022-11-28 - added gpio hal - specified pins as combination of port and pin macro
2022-11-28 spi pins as macro structs
2022-11-28 moved f0 include to stm32 common
2022-11-28 - added button driver - added software encoder driver
2022-11-29 send mouse wheel data over usb
2022-11-30 usb device not global anymore
2022-12-01 - added switch and encoder 3d models
    [encoder_ec10_9mm.step, mouse.kicad_pcb, switch_d2fc-f-7n.step]
2022-12-03 stm32f0 minimal hid example
2022-12-03 added simple pmw3360 interface with working spi
2022-12-18 added encoder draft driver (non working)
2022-12-18 resolved delay sharing conflict for pmw and encoder
    [main.rs]
2022-12-18 - simplified encoder code - split encoder into read and update
2022-12-28 Initial commit with exported f360 design
    [bottom.stl, button.stl, left.stl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]
2023-01-04 fixed slugish encoder bug
    [main.rs]
2023-01-05 - added a debouncer - implemented buttons - renamed encoder struct
2023-01-05 prettier implementation of converting sensor data to hid report
2023-01-05 pulled drivers into a seperate crate
2023-01-05 increase poll rate to 1000hz, change default cpi
2023-01-05 moved from usb-hid to usbd-human-device-interface
2023-01-05 added PWR_FLAGs to pass ERC checks
    [buttons.kicad_sch, mcu.kicad_sch, mouse.kicad_pcb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]
2023-01-06 removed previous fabrication files
    [bom.csv, pp.csv]
2023-01-21 pmw3360: power_up is no longer public
    [mod.rs]
2023-01-22 updated github workflow for pcb
2023-06-04 replace embedded_time with fugit, include Cargo.lock
    [main.rs]
